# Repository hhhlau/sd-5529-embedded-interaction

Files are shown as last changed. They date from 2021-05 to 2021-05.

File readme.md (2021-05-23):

# SD 5529 Embedded interaction workshop
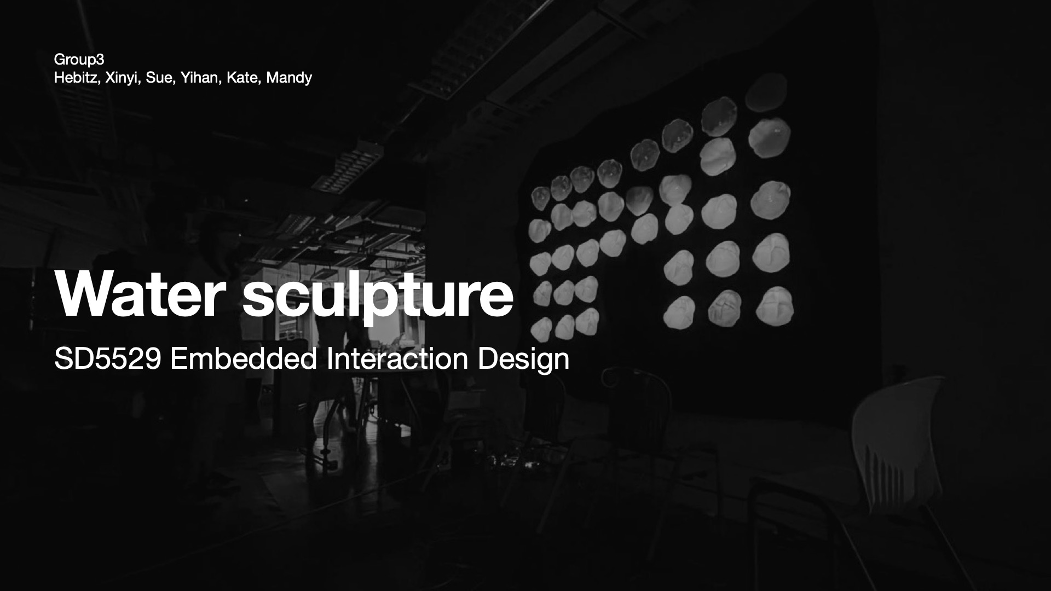
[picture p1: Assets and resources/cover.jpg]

## Component list
- 1 x Arduino Mega 2560 R3
- 5 x 1x8 5V Relay board
- 40 x single bubble unit
- 2 x conductive sheet for capacitive sensing
- 5 x 12V power supply
- 1 x 5V power supply
- 200 feets+ wire
### Single bubble unit component list
The unit is designed with the ease of assemble and installation in mind. For example the legs have room for magnets for easily snapping on metal surface with adjustability; The Cloth-fitting ring allow quick replacement only for the needed parts.

- 3D printed housing
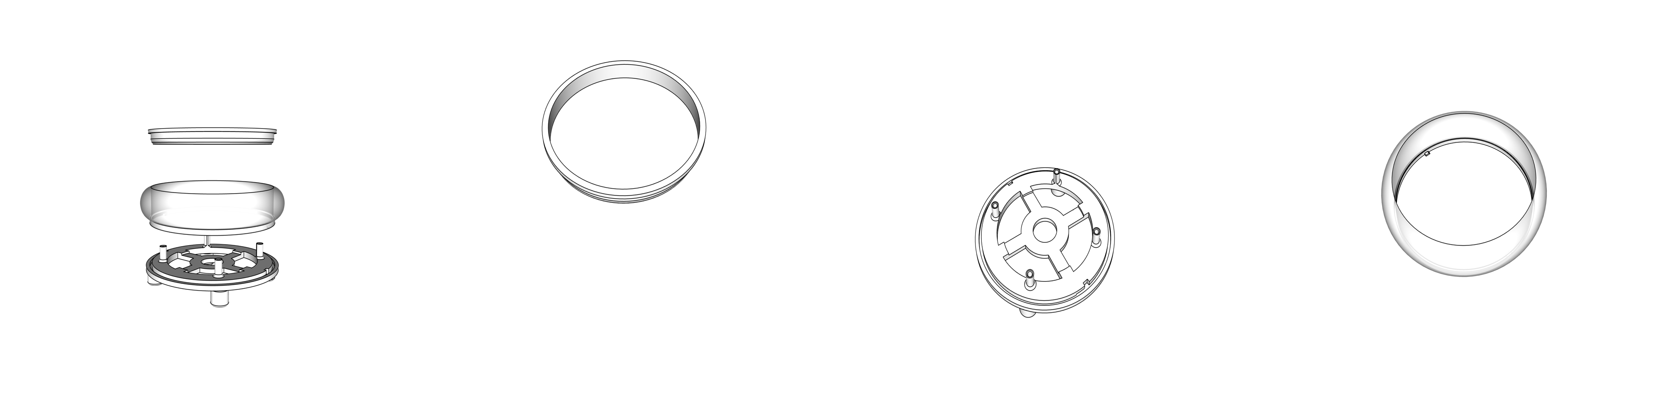
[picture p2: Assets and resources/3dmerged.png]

  - Base unit [(STL file here)](/Assets%20and%20resources/3dprint/base_wleg_0512f.stl)
  - Ring housing unit [(STL file here)](/Assets%20and%20resources/3dprint/ring_housing_merged_0511f.stl)
  - Cloth-fitting unit [(STL file here)](/Assets%20and%20resources/3dprint/ring_lock_fit_0511.stl)
- 12V, 0.45A  computer fan
- 16 x WS2812 RGBW LED in ring PCB
- Sealed cloth bubble [(Paper cut file here)](/Assets%20and%20resources/IMG_3083.png)
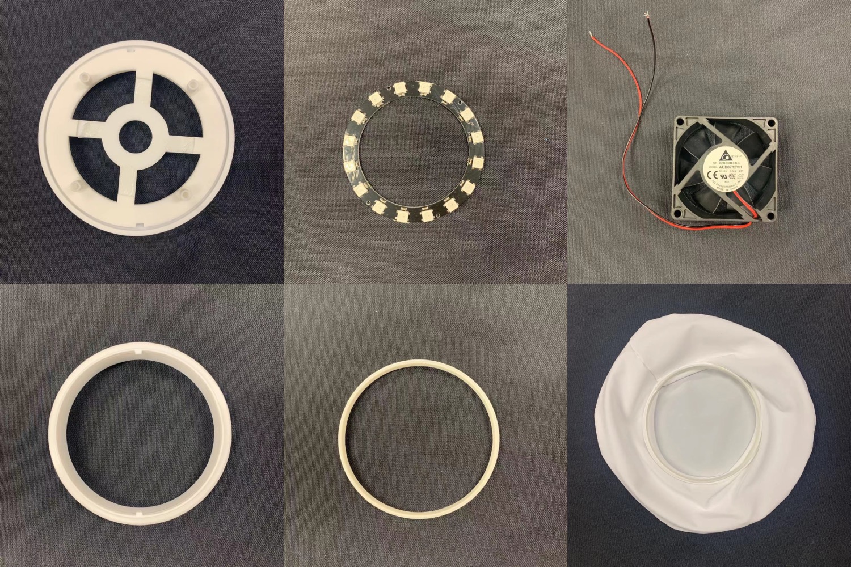
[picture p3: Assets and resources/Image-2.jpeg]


## Wiring and circuit design
- All unit's fans Vcc are connected to relay's NO (Normal open)
- All relay signal pins are connected to Mega's digital pins (40 pins)
- All LED wires are merged in a row basis -> only 5 pins are required for controlling

Simplifed sketch for wiring and circuit design
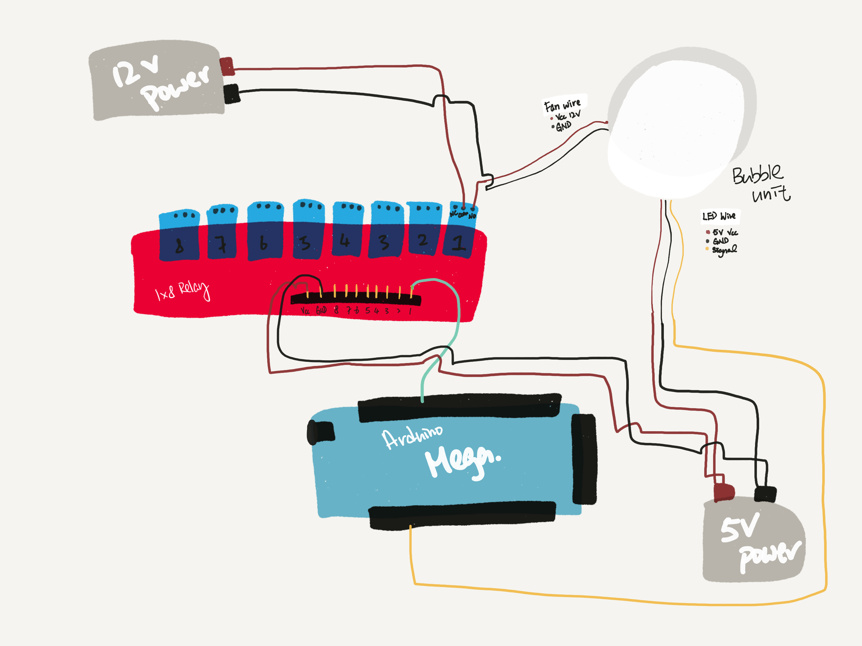
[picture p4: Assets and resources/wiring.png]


## Design sketchs and process
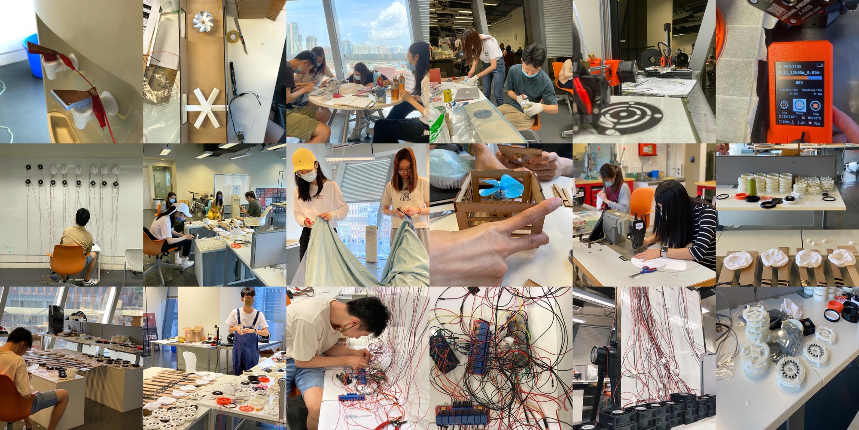
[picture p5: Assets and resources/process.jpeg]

[(Sketches here)](./Assets%20and%20resources/design-logbook.pdf)
## Trimmed logic flow
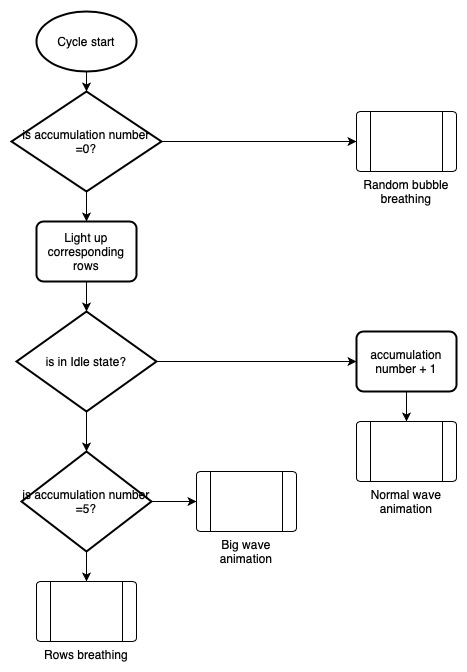
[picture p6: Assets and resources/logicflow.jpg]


## Future improvement
- More animation patterns
- Real unit design, to control each unit with indivial MCU
- To test for 5V fan performance which can simplifed the circuit design

## Special thanks
We are very thankful for the supports and leatures from Mr. Ken Yiu and Tim.
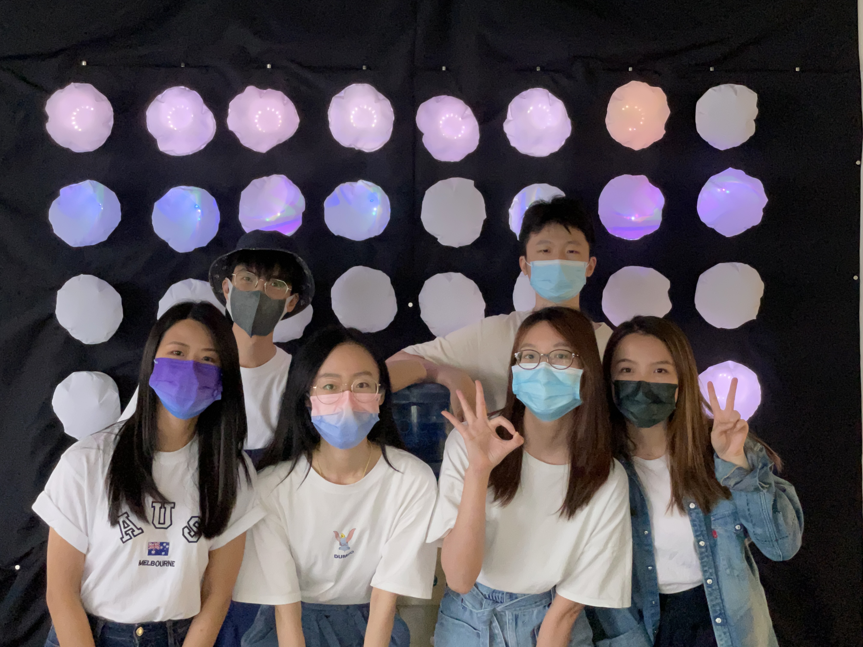
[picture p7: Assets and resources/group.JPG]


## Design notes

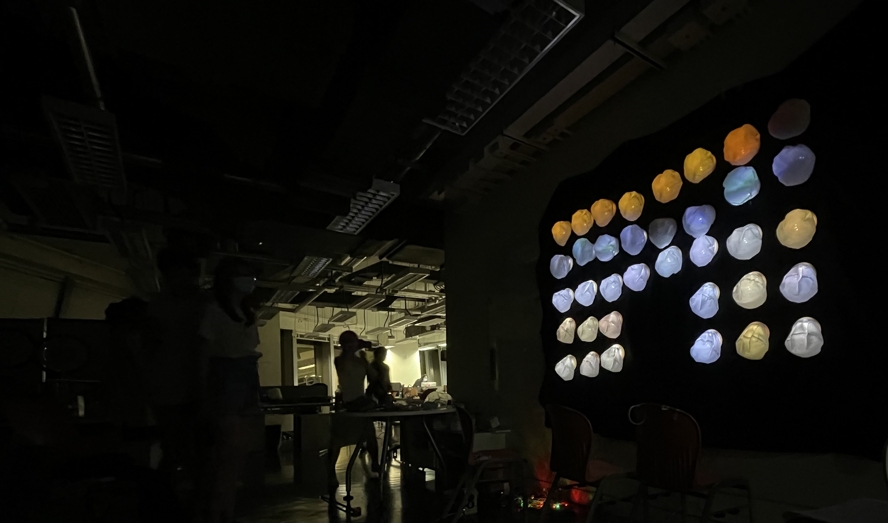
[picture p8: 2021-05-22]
Assets and resources/cover.jpeg

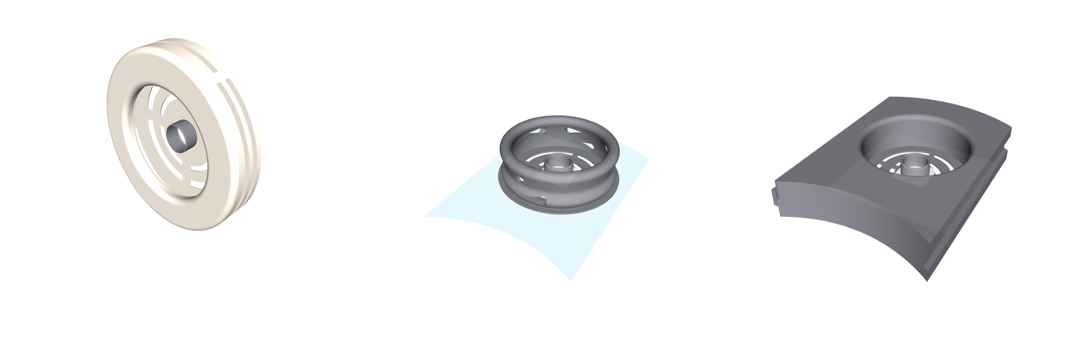
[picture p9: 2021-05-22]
Assets and resources/Image.png

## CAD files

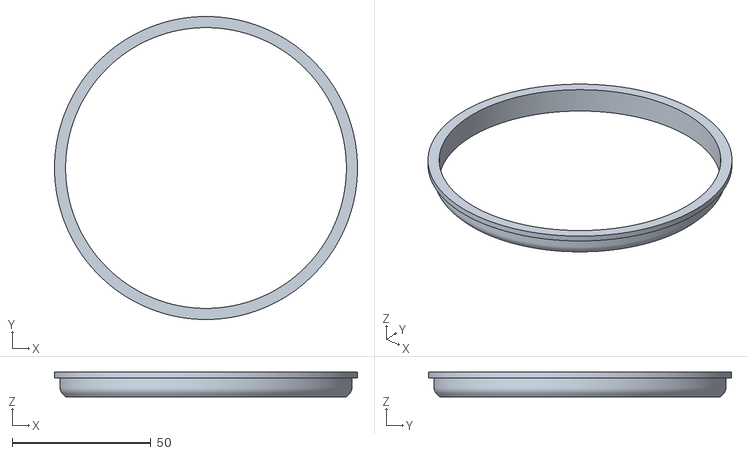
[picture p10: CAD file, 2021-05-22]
Assets and resources/3dprint/ring_lock_fit_0511.stl
109.0 x 109.0 x 8.83

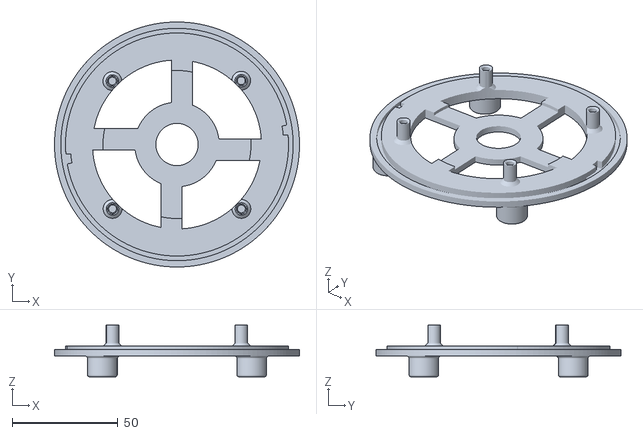
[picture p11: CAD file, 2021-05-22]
Assets and resources/3dprint/base_wleg_0512f.stl
116.0 x 116.0 x 24.5

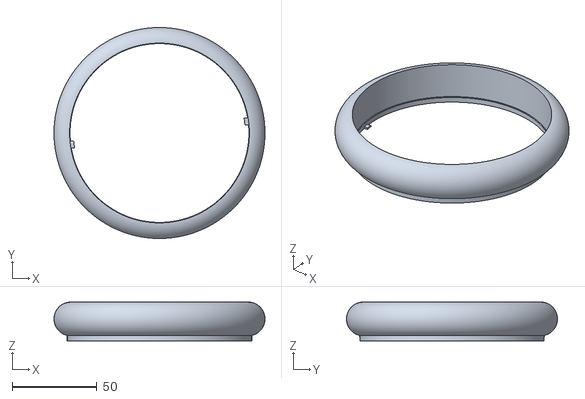
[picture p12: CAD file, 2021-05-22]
Assets and resources/3dprint/ring_housing_merged_0511f.stl
124.4 x 124.4 x 23.0

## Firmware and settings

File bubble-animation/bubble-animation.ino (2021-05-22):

#include <CapacitiveSensor.h>
#include <Adafruit_NeoPixel.h>
#define strip1PIN A0
#define strip2PIN A1
#define strip3PIN A2
#define strip4PIN A3
#define strip5PIN A4
#define NUM_LEDS 16


//DEFINE PIN MATRIX
const int numOfRows = 5;
const int numOfCols = 8;
int delayTime = 300;

int pinMatrix[numOfRows][numOfCols] = {
  {13, 12, 11, 10, 9, 8, 7, 6},
  {5, 4, 3, 2, 22, 23, 24, 25},
  {26, 27, 28, 29, 30, 31, 32, 33},
  {34, 35, 36, 37, 38, 39, 40, 41},
  {42, 43, 44, 45, 46, 47, 48, 49},
};

//DEFINE CAPACITIVE SENSOR
CapacitiveSensor Sensor1 = CapacitiveSensor(50, 51);
CapacitiveSensor Sensor2 = CapacitiveSensor(50, 52);
long SwitchCapa1;
long SwitchCapa2;

int count = 0;
int SwitchState = 0;
int LastSwitchState = 0;

//CREATE NEOPIXEL STRIP
Adafruit_NeoPixel strip1 = Adafruit_NeoPixel(NUM_LEDS, strip1PIN, NEO_GRB + NEO_KHZ800);
Adafruit_NeoPixel strip2 = Adafruit_NeoPixel(NUM_LEDS, strip2PIN, NEO_GRB + NEO_KHZ800);
Adafruit_NeoPixel strip3 = Adafruit_NeoPixel(NUM_LEDS, strip3PIN, NEO_GRB + NEO_KHZ800);
Adafruit_NeoPixel strip4 = Adafruit_NeoPixel(NUM_LEDS, strip4PIN, NEO_GRB + NEO_KHZ800);
Adafruit_NeoPixel strip5 = Adafruit_NeoPixel(NUM_LEDS, strip5PIN, NEO_GRB + NEO_KHZ800);

//DEFINE BLACK COLOR
uint32_t black1 = strip1.Color(0,0,0);
uint32_t black2 = strip2.Color(0,0,0);
uint32_t black3 = strip3.Color(0,0,0);
uint32_t black4 = strip4.Color(0,0,0);
uint32_t black5 = strip5.Color(0,0,0);


void setup() {
  Serial.begin(9600);

  //SET UP MATRIX PIN
  Serial.println("set up start");
  for (int i = 0; i < numOfRows; i++) {
    for (int j = 0; j < numOfCols; j++) {
      pinMode(pinMatrix[ i ][ j ], OUTPUT);
    }//close for i
  }//close for J

  //SET UP NEOPIXEL
  strip1.begin();
  strip1.show();
  strip2.begin();
  strip2.show();
  strip3.begin();
  strip3.show();
  strip4.begin();
  strip4.show();
  strip5.begin();
  strip5.show();

//resetLED();
}

void resetLED(){
  strip1.clear();
  strip2.clear();
  strip3.clear();
  strip4.clear();
  strip5.clear();
//    strip5.fill(black1, 0, 16);
//    strip5.show();
//    strip4.fill(black2, 0, 16);
//    strip4.show();
//    strip3.fill(black3, 0, 16);
//    strip3.show();
//    strip2.fill(black4, 0, 16);
//    strip2.show();
//    strip1.fill(black5, 0, 16);
//    strip1.show();
}

void loop() {

  //READ CAPACITIVE VALUE
  SwitchCapa1 = Sensor1.capacitiveSensor(30);
  SwitchCapa2 = Sensor2.capacitiveSensor(30);
  Serial.print("SwitchCapa1:");
  Serial.println(SwitchCapa1);
  Serial.print("SwitchCapa2:");
  Serial.println(SwitchCapa2);

  //DETECT SWITCH STATE
  if ( SwitchCapa1 > 2000 || SwitchCapa2 > 2000 ) {
    SwitchState = 1;
  } else {
    SwitchState = 0;
  }
  Serial.print("SwitchState:");
  Serial.println(SwitchState);


  //WATERFALL AND LED WHEN TURN ON SWITCH
  if (SwitchState == 1 ) {
    delay(5000);
    waterfall();
  } else {
    if (count == 0 ) {
      randomBubble();
    } else {
      breath();
    }
  }

  //TURN ON LED
  ledEffect();

  //COUNT OF TURNING ON SWITCH
  if (LastSwitchState == 0 && SwitchState == 1 ) {
    count++;
    Serial.print("count:");
    Serial.println(count);
  }

  LastSwitchState = SwitchState;
  delay(500);

  //RECOUNT AFTER FIVE TIMES OF REFILLING
  if (count > 5 ) {
    count = 0;
resetLED();
  }
}

//WATERFALL EFFECT
void waterfall() {
  for (int i = 0; i < numOfRows; i++) {
    for (int j = 0; j < numOfCols; j++) {
      digitalWrite(pinMatrix[i][j], HIGH);
    }//close for j
    delay(delayTime);
  }//close for i

  for (int i = 0; i < numOfRows; i++) {
    for (int j = 0; j < numOfCols; j++) {
      digitalWrite(pinMatrix[i][j], LOW);
    }//close for j
    delay(delayTime);
  }//close for i
}

//down to up multiple line
void bigwave() {
  int waveTime = 2;
  while (waveTime > 0) {
    for (int j = 0; j < numOfCols; j++) {
      for (int i = 0; i < numOfRows; i++) {
        digitalWrite(pinMatrix[ i ][ j ], HIGH);
        delay(100);
      }//close for i
      delay(100);
    }//close for j

    for (int j = 0; j <  numOfCols; j++) {
      for (int i = 0; i < numOfRows; i++) {
        digitalWrite(pinMatrix[ i ][ j ], LOW);
        delay(100);
      }//close for j
      delay(100);
    }
    waveTime--;
  }//close for i
  delay(1000);
  count = 0;
}

void randomBubble() {
  int randI1 = random(0, numOfRows);
  int randJ1 = random(0, numOfCols);
  int randI2 = random(0, numOfRows);
  int randJ2 = random(0, numOfCols);
  digitalWrite(pinMatrix[randI1][randJ1], HIGH);
  delay(500);
  digitalWrite(pinMatrix[randI2][randJ2], HIGH);
  delay(1000);

  digitalWrite(pinMatrix[randI1][randJ1], LOW);
  delay(500);
  digitalWrite(pinMatrix[randI2][randJ2], LOW);
  delay(1000);
}

void breath() {
  for (int i = numOfRows - count; i < numOfRows; i++) {
    for (int j = 0; j < numOfCols; j++) {
      digitalWrite(pinMatrix[i][j], HIGH);
    }//close for j
  }//close for i
  delay(3000);

  for (int i = numOfRows - count; i < numOfRows; i++) {
    for (int j = 0; j < numOfCols; j++) {
      digitalWrite(pinMatrix[i][j], LOW);
    }//close for j
  }
  delay(2000);
}

void middleWave() {

}

void ledEffect() {
  uint32_t blue1 = strip1.Color(255, 255, 255);
  uint32_t blue2 = strip2.Color(255, 255, 255);
  uint32_t blue3 = strip3.Color(255, 255, 255);
  uint32_t blue4 = strip4.Color(255, 255, 255);
  uint32_t blue5 = strip5.Color(255, 255, 255);

  if (count == 1) {
    strip5.fill(blue5, 0, 16);
    strip5.show();
  } else if (count == 2) {
    strip5.fill(blue5, 0, 16);
    strip5.show();
    delay(delayTime);
    strip4.fill(blue4, 0, 16);
    strip4.show();
  } else if (count == 3) {
    strip5.fill(blue5, 0, 16);
    strip5.show();
    delay(delayTime);
    strip4.fill(blue4, 0, 16);
    strip4.show();
    delay(delayTime);
    strip3.fill(blue3, 0, 16);
    strip3.show();
  } else if (count == 4) {
    strip5.fill(blue5, 0, 16);
    strip5.show();
    delay(delayTime);
    strip4.fill(blue4, 0, 16);
    strip4.show();
    delay(delayTime);
    strip3.fill(blue3, 0, 16);
    strip3.show();
    delay(delayTime);
    strip2.fill(blue2, 0, 16);
    strip2.show();
  } else if (count == 5) {
    strip5.fill(blue5, 0, 16);
    strip5.show();
    delay(delayTime);
    strip4.fill(blue4, 0, 16);
    strip4.show();
    delay(delayTime);
    strip3.fill(blue3, 0, 16);
    strip3.show();
    delay(delayTime);
    strip2.fill(blue2, 0, 16);
    strip2.show();
    delay(delayTime);
    strip1.fill(blue1, 0, 16);
    strip1.show();
    bigwave();
  }
}
